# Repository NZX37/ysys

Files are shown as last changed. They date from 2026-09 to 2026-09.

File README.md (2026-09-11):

# YouSnoozeYouSolve Clock


### Inspiration

I wanted to create an alarm clock, right now i rely on my phone and i always end up snoozing until I am late. Other times my alarm wakes me up but it is so easy to snooze, its one button. So i thought why not make snoozing a pain while also "waking" me up?

### Description

The clock features a numberpad, screen and buzzer. The screen shows the time which is updated with wifi when available and internally counted when not connected. You can set alarms which force you to answer math questions to stop the alarm. The case has a glasses holder and watch stand (multifunctionality!!)

### Specifications

BOM: 
- 9x Cherry MX Switches
- 1x XIAO ESP32 C3
- 9x Blank DSA Keycaps
- 8x M3x8 Bolt
- 8x M3 Heatset
- 12x Through-Hole 1N4148 Diodes
-1x 2.25in TFT Screen
-1x 3.3V Piezo Buzzer
-1x 2.54mm 8 Pin Male Header
-8x 20cm Female-Female Jumper Wires

Others:
- Top Case.stl
- Middle Case.stl
- BLAREysys.ino
- Bottom Case.stl

Schematic            |  PCB         |   Case
:-------------------------:|:-------------------------:|:-------------------------:|
 | PCB |

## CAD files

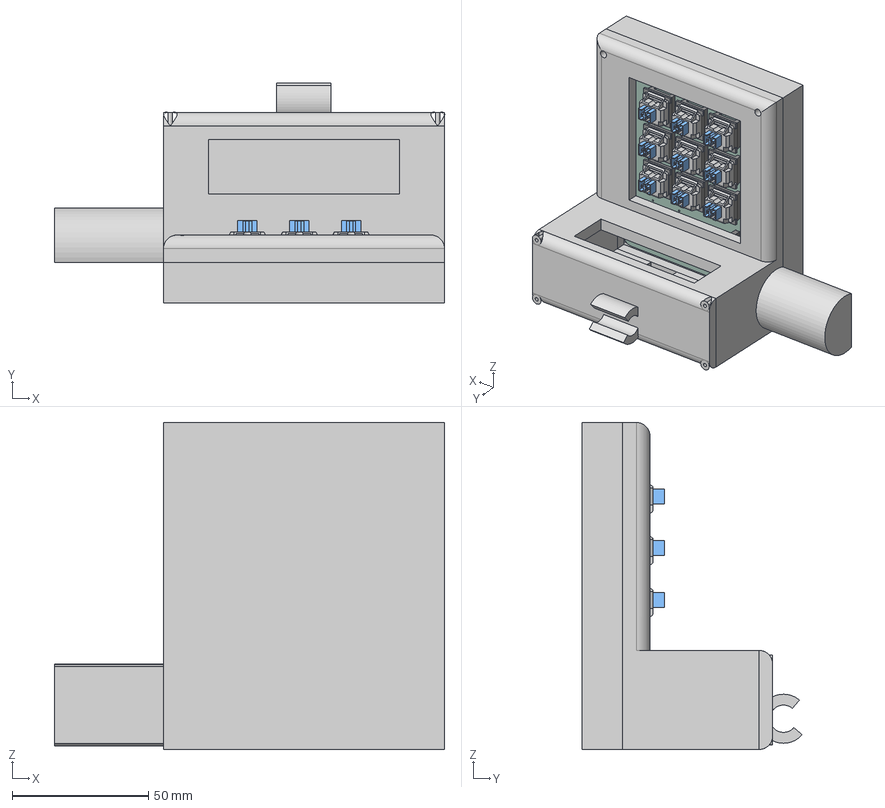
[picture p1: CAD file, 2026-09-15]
CAD/yousnoozeyousolveFULLCASEASSEMBLY.step
143.1 x 80.8 x 120.0 mm
D_DO-35_SOD27_P7.62mm_Horizontal_9 x 9
Buzzer_12x95RM76
PinSocket_1x08_P2.54mm_Vertical_1
you80E6_PCB
Button x 9
Pins x 9

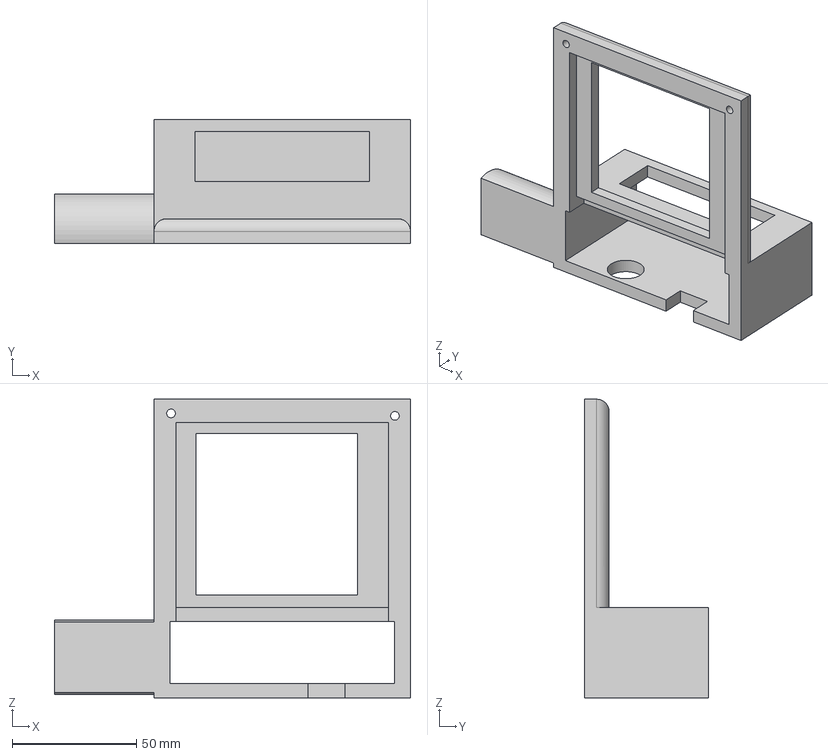
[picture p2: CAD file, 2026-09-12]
Production/yousnoozeyousolveMIDDLECASE.step
143.1 x 50.0 x 120.0 mm

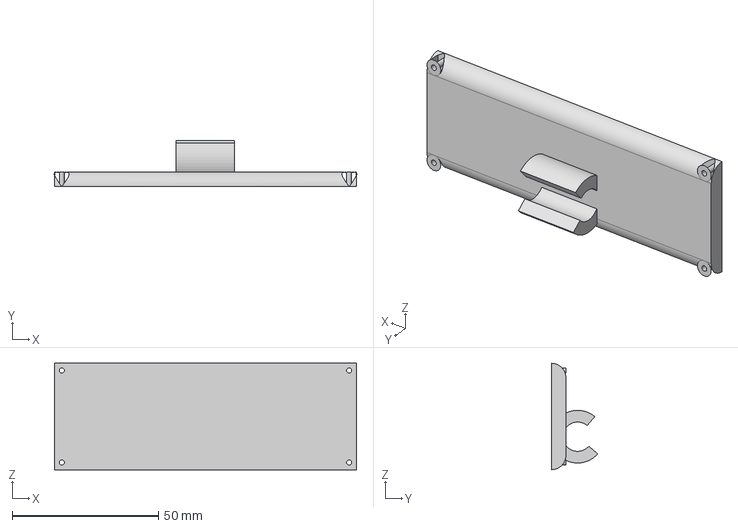
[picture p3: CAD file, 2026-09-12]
Production/yousnoozeyousolveTOPCASE.step
103.1 x 15.8 x 36.4 mm

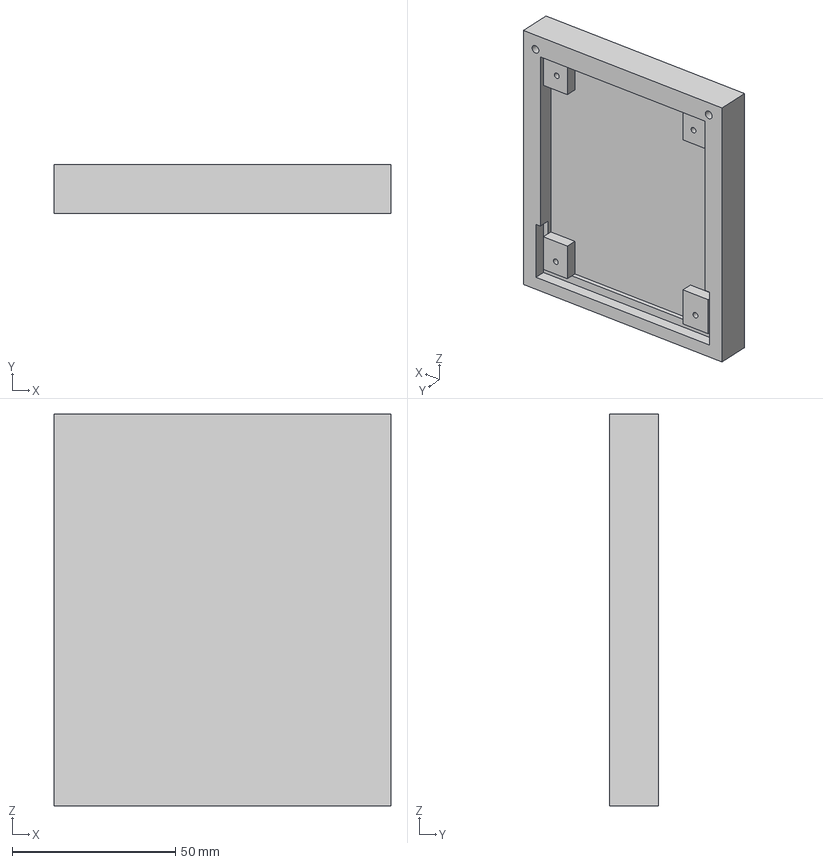
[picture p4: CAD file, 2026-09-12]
Production/yousnoozeyousolveBOTTOMCASE.step
103.1 x 15.0 x 120.0 mm

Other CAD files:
CAD/yousnoozeyousolveFULLCASE.step

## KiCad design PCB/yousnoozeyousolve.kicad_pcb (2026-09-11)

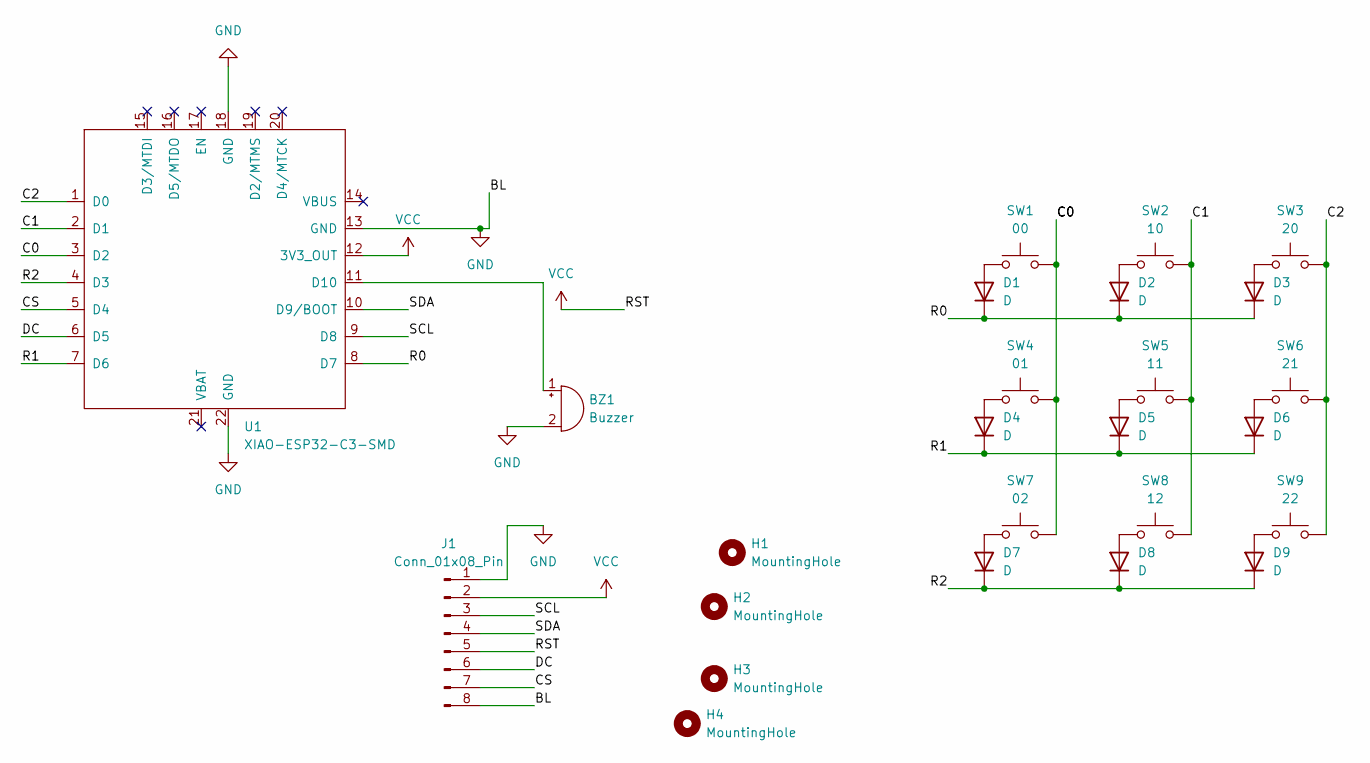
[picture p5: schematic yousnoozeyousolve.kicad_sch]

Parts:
BZ1: Buzzer; Buzzer_12x9.5RM7.6
D1, D2, D3, D4, D5, D6, D7, D8, D9: D; D_DO-35_SOD27_P7.62mm_Horizontal
H1, H2, H3, H4: MountingHole; MountingHole_3.2mm_M3
J1: Conn_01x08_Pin; PinSocket_1x08_P2.54mm_Vertical
SW1: 00; SW_Cherry_MX_1.00u_PCB
SW2: 10; SW_Cherry_MX_1.00u_PCB
SW3: 20; SW_Cherry_MX_1.00u_PCB
SW4: 01; SW_Cherry_MX_1.00u_PCB
SW5: 11; SW_Cherry_MX_1.00u_PCB
SW6: 21; SW_Cherry_MX_1.00u_PCB
SW7: 02; SW_Cherry_MX_1.00u_PCB
SW8: 12; SW_Cherry_MX_1.00u_PCB
SW9: 22; SW_Cherry_MX_1.00u_PCB
U1: XIAO-ESP32-C3-SMD; XIAO-ESP32-C3-DIP

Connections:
/C0: SW1.2, SW4.2, SW7.2, U1.3 (D2)
/C1: SW2.2, SW5.2, SW8.2, U1.2 (D1)
/C2: SW3.2, SW6.2, SW9.2, U1.1 (D0)
/CS: J1.7, U1.5 (D4)
/DC: J1.6, U1.6 (D5)
/R0: D1.1 (K), D2.1 (K), D3.1 (K), U1.8 (D7)
/R1: D4.1 (K), D5.1 (K), D6.1 (K), U1.7 (D6)
/R2: D7.1 (K), D8.1 (K), D9.1 (K), U1.4 (D3)
/SCL: J1.3, U1.9 (D8)
/SDA: J1.4, U1.10 (D9/BOOT)
GND: BZ1.2 (-), J1.1, J1.8, U1.13 (GND), U1.18 (GND), U1.22 (GND)
unnamed: BZ1.1 (+), U1.11 (D10)
unnamed: D1.2 (A), SW1.1
unnamed: D2.2 (A), SW2.1
unnamed: D3.2 (A), SW3.1
unnamed: D4.2 (A), SW4.1
unnamed: D5.2 (A), SW5.1
unnamed: D6.2 (A), SW6.1
unnamed: D7.2 (A), SW7.1
unnamed: D8.2 (A), SW8.1
unnamed: D9.2 (A), SW9.1
VCC: J1.2, J1.5, U1.12 (3V3_OUT)

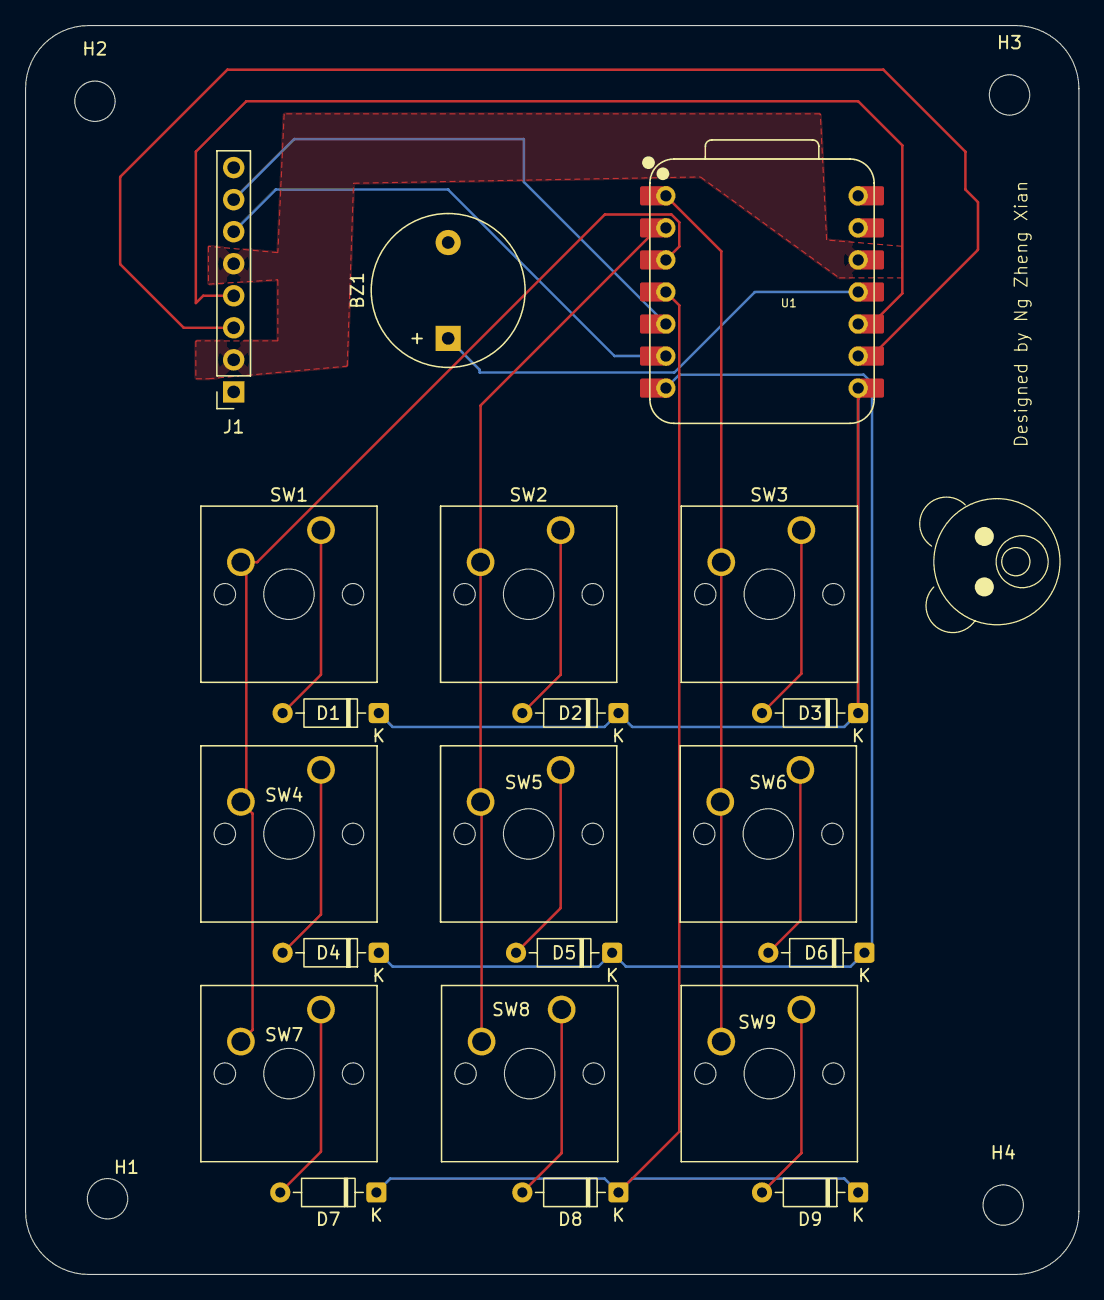
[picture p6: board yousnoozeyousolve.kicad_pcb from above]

Board: 2 copper layers, 83.5 x 99.0 mm, 25 parts (0 on the bottom side), 22 nets.

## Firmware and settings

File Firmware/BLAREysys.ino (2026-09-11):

#include <Adafruit_GFX.h>
#include <Adafruit_ST7789.h>
#include <SPI.h>
#include <Keypad.h>
#include <Preferences.h>
#include <WiFi.h>
#include <time.h>
#include <Fonts/FreeSans9pt7b.h>
#include <Fonts/FreeSerif9pt7b.h>

#define TFT_SCLK 9
#define TFT_MOSI 10
#define TFT_DC   6
#define TFT_CS   5
#define TFT_RST  -1
#define BUZZER   21

class MyST7789 : public Adafruit_ST7789 {
public:
  MyST7789(int8_t cs, int8_t dc, int8_t mosi, int8_t sclk, int8_t rst)
    : Adafruit_ST7789(cs, dc, mosi, sclk, rst) {}
  void setOffsets(uint8_t col, uint8_t row) { _colstart=_colstart2=col; _rowstart=_rowstart2=row; }
};
MyST7789 tft(TFT_CS, TFT_DC, TFT_MOSI, TFT_SCLK, TFT_RST);

const byte ROWS=3, COLS=3;
char keys[ROWS][COLS] = {{'1','2','3'},{'4','5','6'},{'7','8','9'}};
byte rowPins[ROWS]={8,7,4};
byte colPins[COLS]={3,2,1};
Keypad keypad(makeKeymap(keys), rowPins, colPins, ROWS, COLS);

Preferences prefs;

struct Alarm {
  uint8_t hour=7, minute=0;
  bool enabled=false;
  uint8_t numQuestions=3;
  uint8_t snoozeMin=5;
  uint8_t difficulty=1;
};
#define MAX_ALARMS 5
Alarm alarms[MAX_ALARMS];

struct ColorOpt { const char* name; uint16_t val; };
ColorOpt palette[] = {
  {"White", ST77XX_WHITE}, {"Red", ST77XX_RED}, {"Green", ST77XX_GREEN},
  {"Blue", ST77XX_BLUE}, {"Yellow", ST77XX_YELLOW}, {"Cyan", ST77XX_CYAN},
  {"Magenta", ST77XX_MAGENTA}, {"Black", ST77XX_BLACK}
};
const int NUM_COLORS = 8;

const GFXfont* fonts[] = { nullptr, &FreeSans9pt7b, &FreeSerif9pt7b };
const char* fontNames[] = { "Default", "Sans", "Serif" };
const int NUM_FONTS = 3;

struct TZOpt { const char* name; const char* posix; };
TZOpt tzList[] = {
  {"UTC", "UTC0"},
  {"US Eastern", "EST5EDT,M3.2.0,M11.1.0"},
  {"US Pacific", "PST8PDT,M3.2.0,M11.1.0"},
  {"UK", "GMT0BST,M3.5.0/1,M10.5.0"},
  {"Central EU", "CET-1CEST,M3.5.0,M10.5.0/3"},
  {"India", "IST-5:30"},
  {"Singapore", "SGT-8"}
};
const int NUM_TZ = 7;

struct Settings {
  uint8_t fgIdx=0, bgIdx=7;
  bool format24h=true;
  uint8_t fontIdx=0;
  uint8_t tzIdx=0;
} settings;

void loadall() {
  prefs.begin("alarmclock", true);
  prefs.getBytes("alarms", alarms, sizeof(alarms));
  prefs.getBytes("settings", &settings, sizeof(settings));
  prefs.end();
}
void saveall() {
  prefs.begin("alarmclock", false);
  prefs.putBytes("alarms", alarms, sizeof(alarms));
  prefs.putBytes("settings", &settings, sizeof(settings));
  prefs.end();
}

enum Screen { TIME_DATE, ALARM_LIST, ALARM_EDIT, SETTINGS_SCR, ALARM_RINGING, ALARM_PROMPT };
Screen screen = TIME_DATE;

int listIndex = 0;
int editIndex = -1;
int editField = 0;
int ringingAlarm = -1;
int questionsLeft = 0;
String typedAnswer = "";

bool snoozeActive = false;
unsigned long snoozeUntil = 0;
int snoozeAlarmIndex = -1;

const char* alarmEditFields[] = {"Hour","Minute","Enabled","#Questions","Snooze(min)","Difficulty"};
const int NUM_ALARM_FIELDS = 6;
const char* settingsFields[] = {"Text color","BG color","Format 24h","Font","Timezone"};
const int NUM_SETTINGS_FIELDS = 5;

const char* WIFI_SSID = "YOUR_SSID";
const char* WIFI_PASS = "YOUR_PASS";

enum WifiSyncState { WIFI_IDLE, WIFI_CONNECTING };
WifiSyncState wifiState = WIFI_IDLE;
unsigned long wifiAttemptStart = 0;
unsigned long lastSyncAttempt = 0;
const unsigned long SYNC_INTERVAL = 6UL * 60 * 60 * 1000;
const unsigned long WIFI_TIMEOUT = 8000;
bool timeSynced = false;

void applytimezone() {
  configTzTime(tzList[settings.tzIdx].posix, "pool.ntp.org", "time.nist.gov");
}

void startsync() {
  WiFi.begin(WIFI_SSID, WIFI_PASS);
  wifiAttemptStart = millis();
  wifiState = WIFI_CONNECTING;
}

void updatesync() {
  if (wifiState == WIFI_IDLE) {
    if (!timeSynced || millis() - lastSyncAttempt > SYNC_INTERVAL) startsync();
    return;
  }
  if (wifiState == WIFI_CONNECTING) {
    if (WiFi.status() == WL_CONNECTED) {
      applytimezone();
      timeSynced = true;
      WiFi.disconnect(true);
      lastSyncAttempt = millis();
      wifiState = WIFI_IDLE;
    } else if (millis() - wifiAttemptStart > WIFI_TIMEOUT) {
      WiFi.disconnect(true);
      lastSyncAttempt = millis();
      wifiState = WIFI_IDLE;
    }
  }
}

void clearscr() {
  tft.fillScreen(palette[settings.bgIdx].val);
  tft.setCursor(0,0);
  tft.setTextColor(palette[settings.fgIdx].val);
  tft.setFont(fonts[settings.fontIdx]);
}

void drawwifiindicate() {
  uint16_t c;
  if (wifiState == WIFI_CONNECTING) c = ST77XX_YELLOW;
  else if (WiFi.status() == WL_CONNECTED) c = ST77XX_GREEN;
  else c = ST77XX_RED;
  tft.fillCircle(tft.width()-8, 8, 4, c);
}

void drawtimedate() {
  clearscr();
  struct tm t;
  tft.setTextSize(fonts[settings.fontIdx] ? 1 : 3);
  if (getLocalTime(&t)) {
    char buf[16];
    strftime(buf, sizeof(buf), settings.format24h ? "%H:%M:%S" : "%I:%M:%S", &t);
    tft.println(buf);
    tft.setTextSize(fonts[settings.fontIdx] ? 1 : 2);
    strftime(buf, sizeof(buf), "%a %d %b %Y", &t);
    tft.println(buf);
  } else {
    tft.println("No time sync");
  }
  if (snoozeActive) {
    tft.setTextSize(1);
    long remain = (snoozeUntil - millis())/1000;
    if (remain < 0) remain = 0;
    tft.print("Snoozed: "); tft.print(remain); tft.println("s");
  }
}

void drawalarmlist() {
  clearscr();
  tft.setTextSize(fonts[settings.fontIdx] ? 1 : 2);
  for (int i=0;i<MAX_ALARMS;i++) {
    tft.setCursor(0, i*20);
    tft.print(i==listIndex ? "> " : "  ");
    char buf[20];
    snprintf(buf, sizeof(buf), "%02d:%02d %s", alarms[i].hour, alarms[i].minute, alarms[i].enabled?"ON":"off");
    tft.println(buf);
  }
}

void drawalarmedit() {
  clearscr();
  Alarm &a = alarms[editIndex];
  tft.setTextSize(fonts[settings.fontIdx] ? 1 : 2);
  for (int i=0;i<NUM_ALARM_FIELDS;i++) {
    tft.setCursor(0, i*20);
    tft.print(i==editField ? "> " : "  ");
    tft.print(alarmEditFields[i]); tft.print(": ");
    switch(i) {
      case 0: tft.println(a.hour); break;
      case 1: tft.println(a.minute); break;
      case 2: tft.println(a.enabled?"ON":"OFF"); break;
      case 3: tft.println(a.numQuestions); break;
      case 4: tft.println(a.snoozeMin); break;
      case 5: tft.println(a.difficulty); break;
    }
  }
}

void drawsettings() {
  clearscr();
  tft.setTextSize(fonts[settings.fontIdx] ? 1 : 2);
  for (int i=0;i<NUM_SETTINGS_FIELDS;i++) {
    tft.setCursor(0, i*20);
    tft.print(i==listIndex ? "> " : "  ");
    tft.print(settingsFields[i]); tft.print(": ");
    switch(i) {
      case 0: tft.println(palette[settings.fgIdx].name); break;
      case 1: tft.println(palette[settings.bgIdx].name); break;
      case 2: tft.println(settings.format24h ? "24h" : "12h"); break;
      case 3: tft.println(fontNames[settings.fontIdx]); break;
      case 4: tft.println(tzList[settings.tzIdx].name); break;
    }
  }
}

int genop(int difficulty) {
  int maxVal = 1; for (int i=0;i<difficulty;i++) maxVal*=10;
  return random(1, maxVal);
}

int curA, curB; char curOp;

void newmath() {
  Alarm &al = alarms[ringingAlarm];
  curA = genop(al.difficulty);
  curB = genop(al.difficulty);
  const char ops[] = {'+','-','*'};
  curOp = ops[random(0,3)];
  if (curOp=='-' && curB>curA) { int t=curA; curA=curB; curB=t; }
}

void drawmath() {
  clearscr();
  tft.setTextSize(fonts[settings.fontIdx] ? 1 : 2);
  tft.print("Questions left: "); tft.println(questionsLeft);
  tft.setTextSize(fonts[settings.fontIdx] ? 1 : 3);
  tft.setCursor(0,40);
  tft.print(curA); tft.print(' '); tft.print(curOp); tft.print(' '); tft.print(curB); tft.println(" =");
  tft.setCursor(0,80);
  tft.println(typedAnswer);
}

void drawprompt() {
  clearscr();
  tft.setTextSize(2);
  tft.println("Solved!");
  tft.println("# = Stop");
  tft.println("* = Snooze");
}

int computeanswer() {
  switch(curOp) { case '+': return curA+curB; case '-': return curA-curB; case '*': return curA*curB; }
  return 0;
}

void drawscreen() {
  switch(screen) {
    case TIME_DATE: drawtimedate(); break;
    case ALARM_LIST: drawalarmlist(); break;
    case ALARM_EDIT: drawalarmedit(); break;
    case SETTINGS_SCR: drawsettings(); break;
    case ALARM_RINGING: drawmath(); break;
    case ALARM_PROMPT: drawprompt(); break;
  }
  drawwifiindicate();
}

void checkalarm() {
  if (snoozeActive) {
    if ((long)(millis() - snoozeUntil) >= 0) {
      snoozeActive = false;
      ringingAlarm = snoozeAlarmIndex;
      questionsLeft = alarms[ringingAlarm].numQuestions;
      newmath();
      typedAnswer = "";
      screen = ALARM_RINGING;
      digitalWrite(BUZZER, HIGH);
      drawscreen();
    }
    return;
  }
  if (screen==ALARM_RINGING || screen==ALARM_PROMPT) return;

  struct tm t;
  if (!getLocalTime(&t)) return;
  static int lastMinuteChecked = -1;
  if (t.tm_min == lastMinuteChecked) return;
  lastMinuteChecked = t.tm_min;
  for (int i=0;i<MAX_ALARMS;i++) {
    if (alarms[i].enabled && alarms[i].hour==t.tm_hour && alarms[i].minute==t.tm_min) {
      ringingAlarm = i;
      questionsLeft = alarms[i].numQuestions;
      newmath();
      typedAnswer = "";
      screen = ALARM_RINGING;
      digitalWrite(BUZZER, HIGH);
      drawscreen();
      return;
    }
  }
}

void handletimedate(char k) {
  if (k=='9') { screen=ALARM_LIST; listIndex=0; drawscreen(); }
}

void handlealarmlist(char k) {
  if (k=='2') listIndex=(listIndex+MAX_ALARMS-1)%MAX_ALARMS;
  else if (k=='8') listIndex=(listIndex+1)%MAX_ALARMS;
  else if (k=='5') { editIndex=listIndex; editField=0; screen=ALARM_EDIT; }
  else if (k=='9') { screen=SETTINGS_SCR; listIndex=0; }
  else if (k=='*') { screen=TIME_DATE; }
  else return;
  drawscreen();
}

void handlealarmedit(char k) {
  Alarm &a = alarms[editIndex];
  if (k=='2') editField=(editField+NUM_ALARM_FIELDS-1)%NUM_ALARM_FIELDS;
  else if (k=='8') editField=(editField+1)%NUM_ALARM_FIELDS;
  else if (k=='4' || k=='6') {
    int dir = (k=='6') ? 1 : -1;
    switch(editField) {
      case 0: a.hour=(a.hour+24+dir)%24; break;
      case 1: a.minute=(a.minute+60+dir)%60; break;
      case 2: a.enabled=!a.enabled; break;
      case 3: a.numQuestions=constrain((int)a.numQuestions+dir,1,20); break;
      case 4: a.snoozeMin=constrain((int)a.snoozeMin+dir,1,30); break;
      case 5: a.difficulty=constrain((int)a.difficulty+dir,1,3); break;
    }
  }
  else if (k=='9') { saveall(); screen=ALARM_LIST; }
  else if (k=='*') { screen=ALARM_LIST; }
  else return;
  drawscreen();
}

void handlesetting(char k) {
  if (k=='2') listIndex=(listIndex+NUM_SETTINGS_FIELDS-1)%NUM_SETTINGS_FIELDS;
  else if (k=='8') listIndex=(listIndex+1)%NUM_SETTINGS_FIELDS;
  else if (k=='4' || k=='6') {
    int dir = (k=='6') ? 1 : -1;
    switch(listIndex) {
      case 0: settings.fgIdx=(settings.fgIdx+NUM_COLORS+dir)%NUM_COLORS; break;
      case 1: settings.bgIdx=(settings.bgIdx+NUM_COLORS+dir)%NUM_COLORS; break;
      case 2: settings.format24h=!settings.format24h; break;
      case 3: settings.fontIdx=(settings.fontIdx+NUM_FONTS+dir)%NUM_FONTS; break;
      case 4: settings.tzIdx=(settings.tzIdx+NUM_TZ+dir)%NUM_TZ; applytimezone(); break;
    }
  }
  else if (k=='9') { saveall(); screen=TIME_DATE; }
  else if (k=='*') { screen=TIME_DATE; }
  else return;
  drawscreen();
}

void handleringing(char k) {
  if (k>='1' && k<='9') typedAnswer += k;
  else if (k=='*') typedAnswer += '0';
  else if (k=='#') {
    if (typedAnswer.toInt() == computeanswer()) {
      questionsLeft--;
      typedAnswer="";
      if (questionsLeft<=0) {
        digitalWrite(BUZZER, LOW);
        screen = ALARM_PROMPT;
      } else {
        newmath();
      }
    } else {
      typedAnswer="";
    }
  }
  drawscreen();
}

void handleprompt(char k) {
  if (k=='#') {
    screen = TIME_DATE;
  } else if (k=='*') {
    snoozeActive = true;
    snoozeAlarmIndex = ringingAlarm;
    snoozeUntil = millis() + (unsigned long)alarms[ringingAlarm].snoozeMin * 60000UL;
    screen = TIME_DATE;
  } else return;
  drawscreen();
}

void setup() {
  Serial.begin(115200);
  pinMode(BUZZER, OUTPUT); digitalWrite(BUZZER, LOW);
  randomSeed(analogRead(0));

  tft.init(76, 284);
  tft.setOffsets(82, 18);
  tft.invertDisplay(false);
  tft.setRotation(1);

  loadall();
  startsync();
  drawscreen();
}

void loop() {
  updatelync();
  checkalarm();
  char k = keypad.getKey();
  if (k) {
    switch(screen) {
      case TIME_DATE: handletimedate(k); break;
      case ALARM_LIST: handlealarmlist(k); break;
      case ALARM_EDIT: handlealarmedit(k); break;
      case SETTINGS_SCR: handlesetting(k); break;
      case ALARM_RINGING: handleringing(k); break;
      case ALARM_PROMPT: handleprompt(k); break;
    }
  }
  static unsigned long last=0;
  if ((screen==TIME_DATE) && millis()-last>1000) { last=millis(); drawscreen(); }
}

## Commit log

2026-09-05 UPLOAD: files for pcb
    [yousnoozeyousolve.kicad_pcb, yousnoozeyousolve.kicad_sch]
2026-09-11 FILE: Removing outdated files
    [yousnoozeyousolve.kicad_pcb, yousnoozeyousolve.kicad_sch]
2026-09-11 FILE: upload CAD
    [yousnoozeyousolveCASEbottom.stl, yousnoozeyousolveCASEmiddle.stl, yousnoozeyousolveCASEtop.stl]
2026-09-11 FILE: upload PCB
    [yousnoozeyousolve.kicad_pcb, yousnoozeyousolve.kicad_sch, yousnoozeyousolve.step]
2026-09-11 FILE: upload PCB history
2026-09-11 FILE: remove PCB history(git)
2026-09-11 FILE: production files uploaded
    [BLAREysysVERSION4_bom.csv, BLAREysysVERSION4_designators.csv, BLAREysysVERSION4_positions.csv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]
2026-09-12 FILE: change 3d model format
    [yousnoozeyousolveBOTTOMCASE.step, yousnoozeyousolveCASEbottom.stl, yousnoozeyousolveCASEmiddle.stl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]
2026-09-12 FILE: Upload full case assembly
    [yousnoozeyousolveBOTTOMCASE.step, yousnoozeyousolveCASEbottom.stl, yousnoozeyousolveCASEmiddle.stl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]
2026-09-15 FILE: upload gerbers
2026-09-15 FILE: remove old format files
    [BLAREysysVERSION4_bom.csv, BLAREysysVERSION4_designators.csv, BLAREysysVERSION4_positions.csv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]
2026-09-15 FILE: update full assembly
    [yousnoozeyousolveCASEbottom.stl, yousnoozeyousolveCASEmiddle.stl, yousnoozeyousolveCASEtop.stl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]
2026-09-15 FILE: remove not needed files
    [yousnoozeyousolve.step, yousnoozeyousolveBOTTOMCASE.step, yousnoozeyousolveMIDDLECASE.step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]
2026-09-15 FILE: move files
    [yousnoozeyousolveBOTTOMCASE.step, yousnoozeyousolveMIDDLECASE.step, yousnoozeyousolveTOPCASE.step]
